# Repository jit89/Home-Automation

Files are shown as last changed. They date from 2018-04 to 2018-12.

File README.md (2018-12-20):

### Home-Automation: Thinking Differently
With the emergence of the IOT [(Internet of Things)](https://en.wikipedia.org/wiki/Internet_of_things) , automation has become a part and parcel of our daily lives. Starting from lights and fans, people have started to automate almost everything around them. After software giants like Amazon and Google started providing cloud services, people came to use the free resources provided by them to store/log their data and manage them from a distance even without having direct physical contact with the devices.
After this was pretty well-exploited, people started combining the power of machine learning with the existing technology. With rapid improvement in hardware and GPU's becoming cheap, it has become quite easy for an individual to learn, test out and contribute to the advancement of machine learning. Powerful methods like use of [deep learning](https://en.wikipedia.org/wiki/Deep_learning) in visual image processing, natural langugage processing etc has made this existing technology even more smarter. Popular home assistants like Amazon [Alexa](https://developer.amazon.com/alexa) etc, by making their API's open sourced have encouraged development in home automation even more.
### Why re-invent the wheel then ?
You might ask, well a lot of people have spent years writing and perfecting their techniques, why not build our application atop them ? Why do we even need to think about something from scratch where we have already progressed so far ? The answer is very simple, in fact this the reason for which we took up this project. We couldn't agree well with the existing idea of automation. I know, there are some brilliant projects out there at [Instructables](https://www.instructables.com/), [Hackaday](https://hackaday.com/) and [Hackster](https://www.hackster.io/) etc where people have put a lot of effort making a very neat and appealing project and I appreciate their effort. But controlling lights, fans, switches and other power ports using bluetooth, WiFi and other technologies through a custom designed Android/iOS application may be excellent but they are over exploited already. Yeah, you can switch on your Television and washing machine, turn off the radio, feed your pet, monitor the weather while sitting on your couch while watching your favourite series on Netflix but this has already been done, right ? We are already living those days, but what if your TV knew when do you watch it mostly ? What if your lights and fans knew when to turn on and when not to so they could save the maximum power when you are not in in your room ? That is much better than controlling your lights, fans, television etc through a Bluetooth controlled Arduino or telling Alexa to switch it on/off for you. My point is, the devices which we use everyday should develop some kind of intelligence so that they can know when they are used mostly and thus turn themselves on during those hours without you, manually switching it on. This is exactly what we try to do here.
### The Idea
Keeping aside all big talks, our aim is simple, designing a system that learns to map user behaviour. Citing a small example here, Suppose, you live alone in small apartment with only three appliances in your house, two lights and a fan, lets call them **LIGHT 1**, **LIGHT 2** and **Fan**. Now, consider the following case:
* You wake up at 07:00 (7:00 AM) hours and do your daily chores.
* You leave for office at 08:00 Hours (8:00 AM).
* You return home at 19:00 Hours (7:00 PM).

You follow the above routine on most working days. After waking up (i.e is after 07:00) hrs and before leaving for your office at 08:00 hrs suppose you use light 1 and the fan. After returning from office, you use all three of the appliances. Since, you dont have many switches in the room, you don't have much room for exploring more options, as a result you follow a similar routine everyday.
If we use our prototype here, what our system will do is, it will learn when and how much you used the appliance and from the very next day try to follow the same routine as followed by you the previous days. This wont be done from the start, after you install the prototype it will observe you for a day which we call as the **observation period**.
### The Brief Technicalities
Its time for us now, to dive into brief technical details. Our application is actually a room automation module which is used to automate your room, this module provides a drop in replacement for your switchboard so that you do not need to touch your switch board again. The form factor of the module will be so made that it retro-fits behind your switchboard. You can then control the functionalities of the physical switches of your switchboard through a smartphone application, just like any other home automation device. But Wait! There is much more to it. Apart, from controlling them at your own will from the smartphone application you can very well control them by the physical switches if you like. We are not taking away your rights over your switchboard! This, comes in handy if the module or the smartphone application goes haywire, you can anyway use your switches without any worry. Wait, There is even more! Like I said before, the system takes into account your choices of switching appliances on and off both through the physical switches and through the smartphone device. After it has gathered enough data and after you allow it to, it will predict what appliance you might switch on at a certain time of the day and switches on that appliance. Its like, you come home everyday at 19:00 hrs (7:00 PM) and switch on the fan hanging over your sofa, but one day you find out as soon as you come home at or after 19:00 hrs (7:00 PM) the fan switches on by itself!
### Some Additional features
1. A lot of features have been mentioned already but what I would like to add here is, such a system works by mapping user action throughout the day and reproducing them later. Well, you might say, OK, I agree that someone can maintain some coherence in his/her routine for a day or two, but someone cannot follow the same pattern for days after days, for Heavens's sake we are not machines! We, too thought about this, how you will deal with your home appliances tomorrow cannot be exactly predicted by observing how you dealt with them today, we can only get a rough idea. If you observe someone for a day, the conclusion you will reach will be an abstract idea, like:
  > "Ohh, so he likes to leave all lights on during the night",

  or maybe something like this:

  > "Ohh, he switches on more tubelights in the night than in the day",

  or, more likely something like this:

  > "I bet, he uses only half of the appliances he has, in his house".

These are all rough estimates which might be true for a day or two but cannot be guaranteed over a longer period of time. So, How do you get make good estimtes ? Well you keep a watch more frequently and try to understand how much the behaviour of the user differs each day and update your observation accordingly. Our system exactly does that, it keeps a note of your usage behaviour very frequently and tries to draw and inference from that, after a day is over it updates its observations.

2. Since, the system follows the user's behaviour and updates itself as soon as the user's behaviour changes, the device isnt affected by the change of seasons, timezones, geographic locations etc. It all depends on how you use it. 
### How is it being done ?
Before starting, let me tell you quite frankly, that the idea is still in the developmental stage and a lot of community help is required to further polish it. Only a working prototype is being developed here. Our goal is to make a small, easy-to-interface  embedded module made from commonly available parts which will be having enough intelligence to provide descisions based on observing a particular user.
* Lets, talk about the hardware first, We are using [ESP8266-ESP12](https://www.elecrow.com/download/ESP-12S_User_Manual.pdf) [Wemos D1 Mini](https://wiki.wemos.cc/products:retired:d1_mini_v2.2.0) here. 
  * Three pins are configured as outputs for controlling a relay through a BJT (Bipolar Junction Transistor) or probably a MOSFET in the future, for switching high voltage appliances. 
  * A [PIR (Passive Infrared Sensor)](https://cdn-learn.adafruit.com/downloads/pdf/pir-passive-infrared-proximity-motion-sensor.pdf) is used to detect the occupancy of a person in the room, the output of the PIR sensor is fed to a pin configured as input. 
  * For storing the data permanently an i2c [FRAM](http://www.cypress.com/file/136491/download) will be used, FRAM being chosen particularly because of its fast write time and very large read/write cycles in comparison to any eeprom or flash memory.
* The software used to program the ESP is micropython. They are seriously brilliant guys who made micropython possible. I would suggest you to take a look at ther [repository](https://github.com/micropython/micropython) for more information. The software will manage all the afore mentioned hardware. A small single neural network with a single hidden layer will be employed to predict the appliance which needs to be turned on/off, given a particular time and a state (i.e the person is in the house or not). Please note that we are not doing a time series prediction anyway, we are not trying to model the user's behaviour as time series beacuse such a series would be very stochastic, it would more and more difficult to find a pattern in the user's behaviour if the observations are taken for a very long period of time. Our model is based on the assumption that the chance of the user,  using our system, to repeat his/her routine is maximum the very next day, i.e if today is Tuesday, there is more probability of the user to follow a similar routine for Wednesday, but would be very difficult to say in advance that the user will follow a similar routine on Saturday or Sunday. Obviously, hard coding such an assumption is a very naive choice indeed because there can be many cases which might simply outrun the assumption, but for the sake of simplicity such an assumption is made. But some other methods are also employed to alleviate the issue. 
* A smartphone application is being developed too for user access through a smartphone.
* A server side script which the ESP8266 and the smartphone application will connect to enable the user to acces the home appliances from anywhere in the world. The server side script will be written in CPython. We intend to buy a domain for this purpose.

### The occupancy detection algorithm
Since, we have already talked about the hardware and the software separately, its time we combine both of them to state an algorithm followed by the system. A little note here, we are using PIR to detect if a person is present in the room, once the person gets out of his/her room we switch off the appliances present in the room when the user gets back inside, the appliances switch on. But do all of them switch on ? No, only those appliances switch on, which have been switched on by the user in the previous days when the system was observing the user during the **observation period**. This essentially means, once you come inside of your room you need not switch on your home appliances yourself, the system does it for you, it remebers what appliances you had switched on during that time in the previous days, and switches on that appliance which has a high probability of being switched on by you during that time.
Now we can discuss about the occupancy detection algorithm, our idea is inspired from [this](https://www.researchgate.net/publication/308007740_Predicting_room_occupancy_with_a_single_passive_infrared_PIR_sensor_through_behavior_extraction) paper. The paper discusses sophisticated filtering and detection methods none of which are employed here, still its worth a read if you are into mathematics and love reading articles related to applied machine learning. The only part of our idea taken from the paper is that we are using only a single PIR. What we previously did was to keep two PIR's kept at a distance from each other in a fashion that is described in the left portion of the picture below:
    
    Our earlier layout                                  |                      PIR Filed of Vision       
    --------------------------------                    |                   -
          ---                                           |                 -
      PIR 1  |--                                        |               -
             |  |                                       |             -
             |--                                        |           --
          ---                                           |  ---    -    --
                                                        |     |--        --
    ----------------------------------                  | PIR |  |         -    120*
                                                        |     |--          -
    ----------------------------------                  |  ---    -       --
          ---                                           |           -   --
      PIR 2  |--                                        |             -
             |  |                                       |                -
             |--                                        |                   -
          ---                                           |                     -
    ----------------------------------                  |  

So, whenever someone crossed PIR 1, the output pin of the PIR 1 became high, and then after he crossed PIR 2, its output became high, we connected the output of the two PIR's to an Arduino and enabled both the arduino pins to fire interrupts whenever the state of the pin changed from low to high. Inside the interrupt service routine (ISR), which is the section of the code that gets executed during an interrupt occurs, we stored a timestamp. Now, suppose, when the person crosses PIR 1 we store the time stamp in a variable named **t1**, now when he crosses the PIR 2, we store the timestamp in a variable caleed **t2**. Now, if t2 is greater than t1, it means the PIR 1 fired before the PIR 2 and the person crossed PIR 1 first, we classified this movement as entry, if the opposite happened i.e if t1 was greater than t2, that is the person approached PIR 2 first and then PIR 1, we classified it as an exit. The method is simple enough but has many drawbacks like you have to cross the two PIR's linearly, also the field of vision of the PIR's are 120 degrees as drawn on the right side, so placing two PIR's side by side will cause their field of visions to overlap and it may often happen that the two PIR's fire together, to avoid that, we used a cylindrical enclosure to cover the PIR's partially, so that their field of vision's are forcibly narrowed, this wasn't a good practice and reduced the efficiency of PIR sensors and sometimes leading them to not fire at all.

After this, we came to the idea of using a single PIR after reading that research paper which I talked about earlier. We still connect the output of the PIR to our ESP and enable the pin to detect a rising edge. What we only dont do now is use another PIR, we let the single PIR fire freely on its own. If I haven't already talked about the delay in the PIRs, I'm going to talk about it now, if you have used a PIR before, then you might be knowing that after the PIR output pin has become high it stays high for a certain amount of time. While the PIR output is high it caanot detect any motion during that period. So, this is the minimum amount of time every PIR will wait before being available to take another reading. The delay varies across PIRs and I have rarely found two PIR sensors having the exact same amount of delay. The delay can be increased as well using the preset given in the PIR sensor board but for our use we keep it at its minimum. 
What we do now is, **sample the PIR output pin after every 5 seconds**, we define a quantity called activity which sees how many times we get a HIGH output from the PIR during a given span of time, here, the span being 1 hour. The PIR will fire only when a person moves inside the room. Thus if the person becomes motionless the PIR won't output a HIGH, so counting the HIGH states sampled from the PIR means to indirectly measure how much the person makes movement during his entire stay inside the room. But we are not just counting the number of HIGH outputs from the PIR and dividing it by 3600 seconds to get an average rate of HIGH fires or activity of the person. Why ? Because averaging out is a good solution to get a rough measure of the user activity inside the room but vital information like the minimum rate and the maximum rate during the person's stay in his room in an hour cannot be found out from the average. So, we keep track of the changes in the activity variable and keep two other variables for storing the maximum and the minimum activity during an hour of observation.

We will try to follow the below mentioned tree:

    ----root
        |----Hardware
                |----Schematics, datasheet and pcb design files
        |----Micropython
                |----Micropython code for the Esp
        |----Server
                |----Server side scripts
        |----Smartphone_Application
                |----All documentation related to the smartphone application

### Support
We would appreciate any help provided from your side in designing and developing this idea. We also welcome all kinds of comments and suggestions provided to us.

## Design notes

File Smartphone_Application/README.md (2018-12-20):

<h1>HOME APP</h1>

## Xml Formatting
In designing xml of this app navigation drawer layout is used
* All mainscreen elements are inside a frame layout.
* A linear Layout is used after frame Layout to support elements
* Several layers of layouts were used to hold various elements
A rough map of the xml layout  is given below:
    
    ----drawer_layout
                
             |--Frame_layout
                   |---Relative_layout
                           
                           |---Linear Layout(H)
                                        |--ImageButton
                                        |--TextView
                                        |--Imagebutton
                           |---Linear Layout(H)
                                        |--Linear Layout(v)
                                                    |--ImageButton
                                                    |--TextView
                                                    |--Seekbar
                                        |--Linear Layout(v)
                                                    |--ImageButton
                                                    |--TextView
                                                    |--Seekbar
                           |---Linear Layout(H)
                                        |--Linear Layout(v)
                                                    |--ImageButton
                                                    |--TextView
                                                    |--Seekbar
                                        |--Linear Layout(v)
                                                    |--ImageButton
                                                    |--TextView
                                                    |--Seekbar
                           |---TextView
                           |---Linear Layout(H)
                                        |--ImageButton
                                        |--ImageButton
                                        |--ImageButton
        
        |--Navigation_View
                        |---Header
                        |---Drawer Views
        
        |--Splashscreen

## MainActivity
* Separate boolean variables are assigned for every individual appliances of every room.
* On appliance button click it checks the concerned variable state and change the state accordingly 
and also change the text view.
* On Button or seekbar change it calls a method which sends a json to a hardcoded url.
* On room Button click it shows the status of the appliances of that room.

## Screenshots
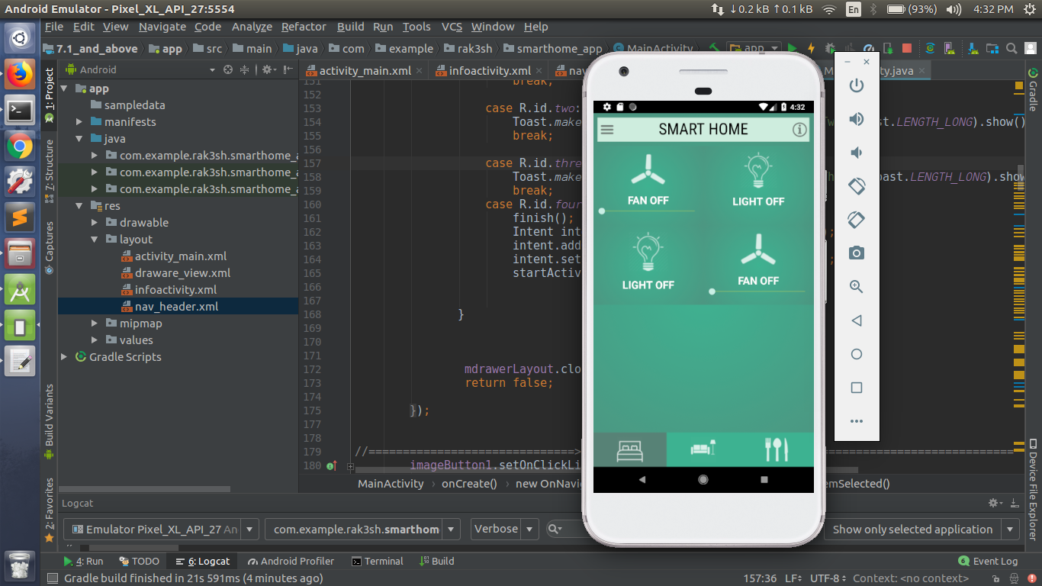
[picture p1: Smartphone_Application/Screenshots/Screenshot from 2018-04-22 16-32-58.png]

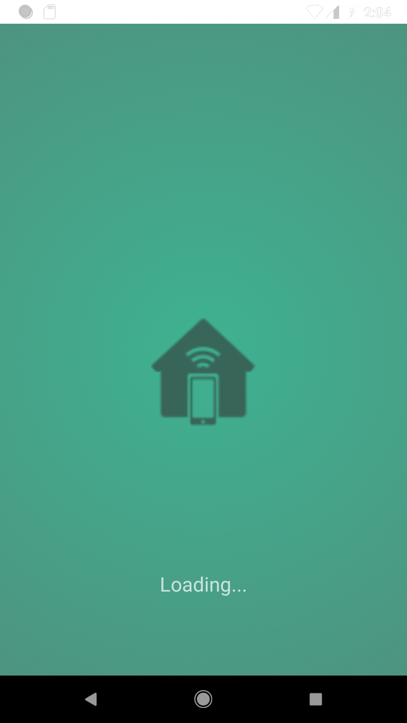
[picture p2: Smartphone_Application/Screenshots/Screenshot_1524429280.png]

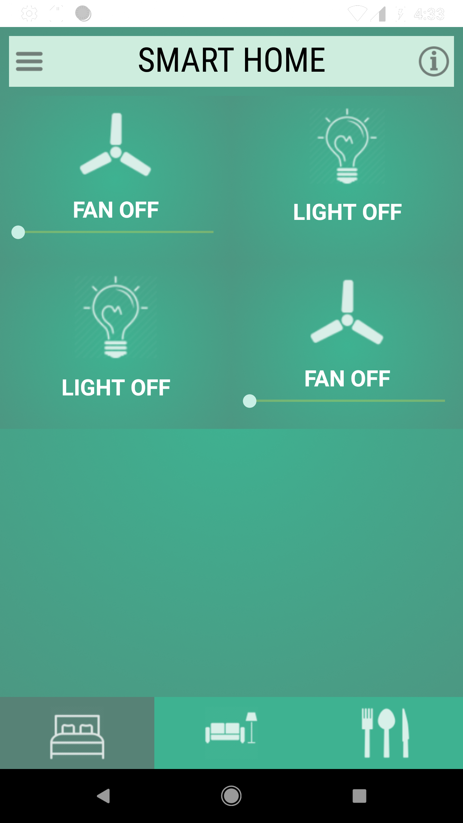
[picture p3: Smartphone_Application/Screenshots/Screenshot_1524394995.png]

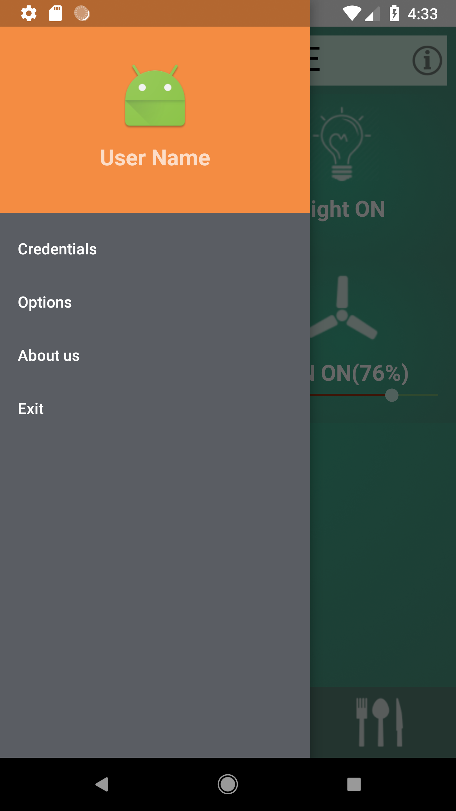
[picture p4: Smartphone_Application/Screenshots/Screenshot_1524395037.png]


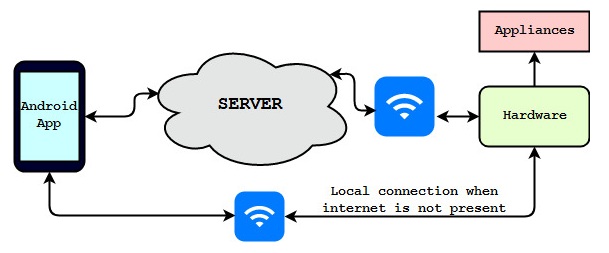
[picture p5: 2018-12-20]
Hardware/rev_1.0/Block_Diagrams/system.jpg

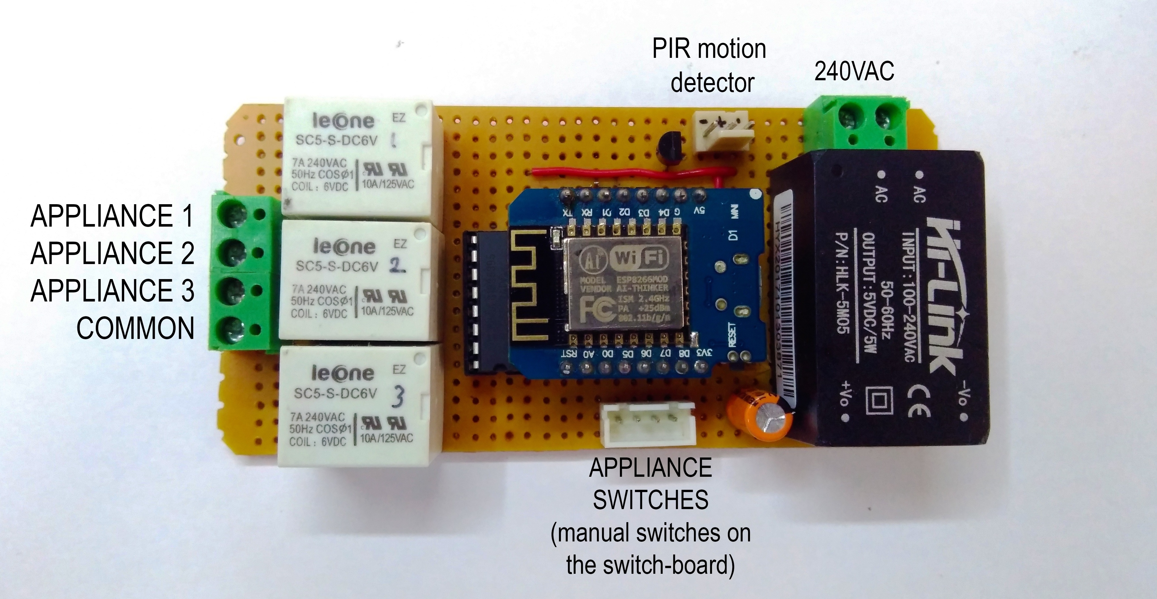
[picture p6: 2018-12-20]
Hardware/rev_1.0/Block_Diagrams/hardware_overview.jpg

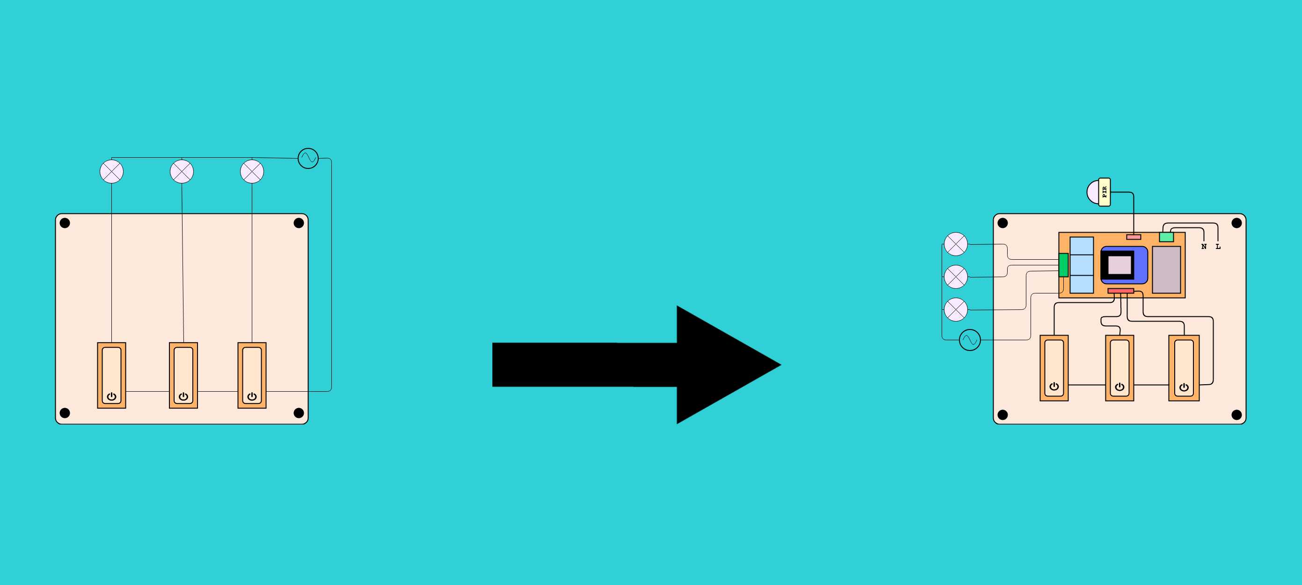
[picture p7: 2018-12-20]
Hardware/rev_1.0/Block_Diagrams/state_change.png

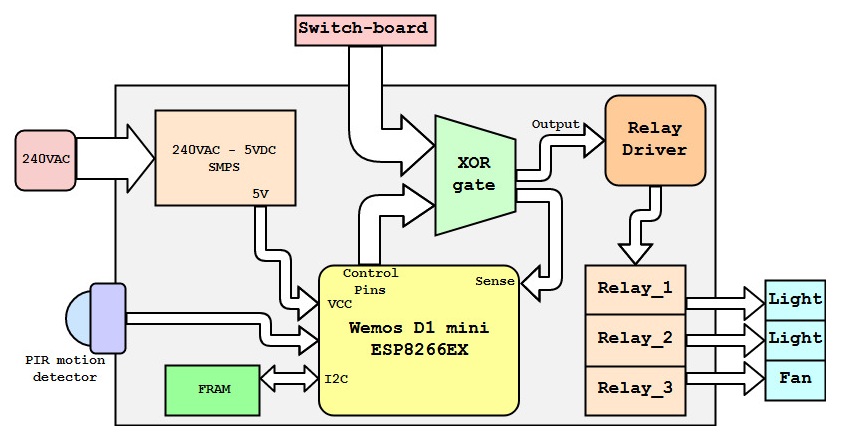
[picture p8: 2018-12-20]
Hardware/rev_1.0/Block_Diagrams/hardware_block_diagram.jpg

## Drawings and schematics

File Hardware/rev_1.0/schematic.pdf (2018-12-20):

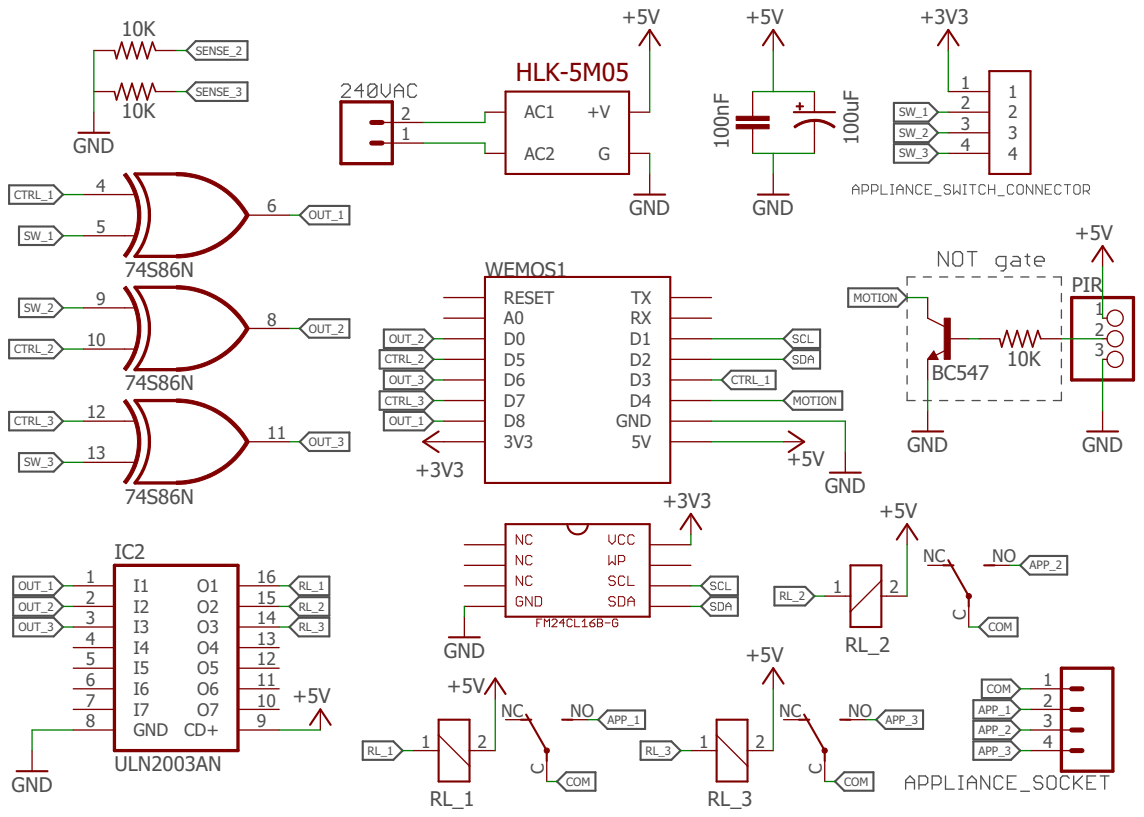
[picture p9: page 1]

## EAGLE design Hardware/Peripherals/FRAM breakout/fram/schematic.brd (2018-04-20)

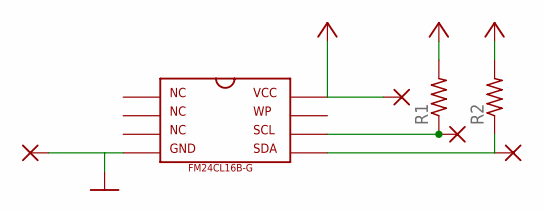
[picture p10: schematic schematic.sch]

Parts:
GND: SMD2; SMD1,27-2,54
R1, R2: R-US_M0805; M0805
SCL: SMD2; SMD1,27-2,54
SDA: SMD2; SMD1,27-2,54
U$1: FM24CL16B-G
VCC: SMD2; SMD1,27-2,54

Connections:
+3V3: R1.2, R2.2, U$1.8, VCC.1
GND: GND.1, U$1.4
unnamed: R1.1, SCL.1, U$1.6
unnamed: R2.1, SDA.1, U$1.5

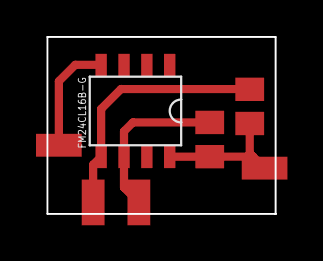
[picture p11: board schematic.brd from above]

Board: 2 copper layers, 12.7 x 9.8 mm, 7 parts (0 on the bottom side), 4 nets.

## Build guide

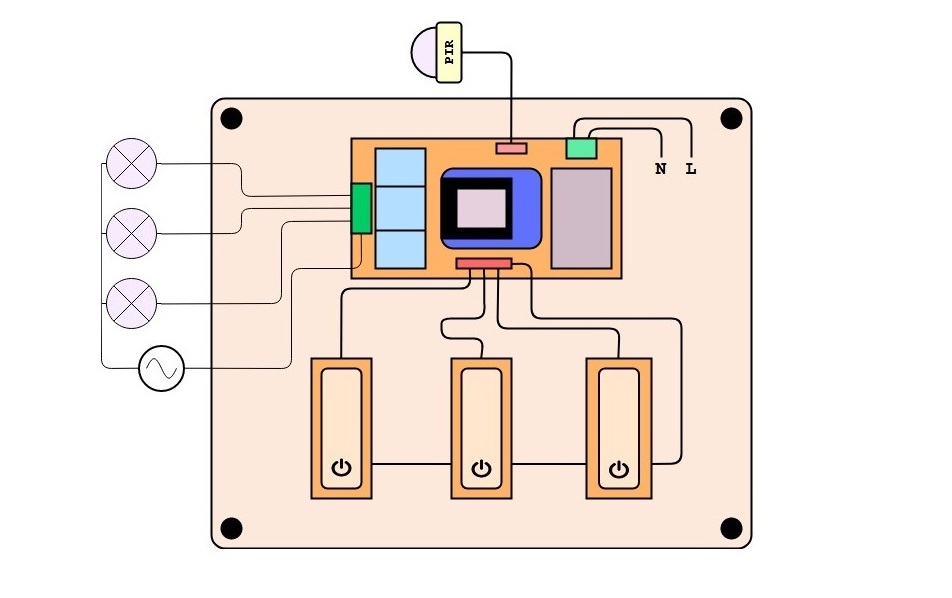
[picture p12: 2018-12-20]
Hardware/rev_1.0/Block_Diagrams/wiring.jpg

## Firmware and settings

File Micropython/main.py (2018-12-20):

import machine
import network
import urequests
import utime
from machine import Pin

from Micropython.appliance import Device
from Micropython.utils import rtc_init, station, timed_function

rtc = machine.RTC()
i2c = machine.I2C(sda=Pin(4), scl=Pin(5), freq=400000)

sta = network.WLAN(network.STA_IF)
ap = network.WLAN(network.AP_IF)

old_req = None


def test_device_stagnancy(device_list):
    for device in device_list:
        device.calibrate_stagnancy()


@timed_function(500)
def parse_request(device_list):
    global old_req

    try:
        req = urequests.get('http://phpexampl.000webhostapp.com/test.php?opt=x')
    except:
        req = urequests.get('http://phpexampl.000webhostapp.com/test.php?opt=x')

    req = req.json()

    if req != old_req and old_req is not None:

        if req['app11'] != old_req['app11']:
            device_list[0].toggle_state()

        if req['app21'] != old_req['app21']:
            device_list[1].toggle_state()

        if req['app31'] != old_req['app31']:
            device_list[2].toggle_state()

    old_req = req


@timed_function(1000)
def print_debug_info(device_list):
    for device in device_list:
        print(device._output_pin.value())


def init():
    """All initialisations here"""

    # device_timer = machine.Timer(-1)

    output_pins = (00, 14, 13)  # Define your output pins here
    input_pins = (15, 16, 12)  # Define your input pins here

    devices = [Device(Pin(In), Pin(Out)) for In, Out in zip(input_pins, output_pins)]

    #   Set all the devices to zero state at first
    for device in devices:
        device.set_state(0)

    # ssid, password = access_point(sta, ap)
    station(sta, ap, 'D-Link', 'ik1224kln')

    rtc_init(rtc, sta)
    print(utime.localtime())

    # device_timer.init(period=60000, mode=machine.Timer.PERIODIC, callback=lambda _: test_device_stagnancy(devices))

    return devices


def main():
    # init()

    device_list = init()

    while True:
        """All routines that are repeated"""
        parse_request(device_list)
        print_debug_info(device_list)
        print('#')

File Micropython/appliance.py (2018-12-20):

import machine
import utime


# noinspection SpellCheckingInspection
class Device(object):
    """
    Device class for the appliances
    :param: _input_pin
    :type: machine.Pin object

    :param: _output_pin
    :type: machine.Pin object

    :return: None
    """

    def __init__(self, _input_pin, _output_pin):

        if isinstance(_input_pin, machine.Pin):
            self._input_pin = _input_pin
            self._input_pin.init(mode=machine.Pin.IN)
        else:
            raise TypeError("Expected argument 1 to be of type machine.Pin but got type {}".format(type(_input_pin)))

        if isinstance(_output_pin, machine.Pin):
            self._output_pin = _output_pin
            self._output_pin.init(mode=machine.Pin.OUT)
        else:
            raise TypeError("Expected argument 2 to be of type machine.Pin but got type {}".format(type(_output_pin)))

        self.DEVICE_DATA_STORAGE_ADDRESS = 80

        self._data = bytearray(24 * 7)  # Represent 24 hours * 7 days as a contiguous block of bytes

        self.on_time = 0
        self.oldHour = utime.localtime()[3]

    def get_state(self):
        """
        Returns the state of the _input_pin
        :param: None
        :return: Boolean
        """
        # noinspection PyArgumentList
        return self._input_pin.value()

    def set_state(self, value):
        """
        Sets the state of the _output_pin
        :param: value
        :type: Boolean
        :return: None
        """
        self._output_pin.value(value)

    def toggle_state(self):
        """
        Toggles the state of the _output_pin
        :param: None
        :return: None
        """
        self._output_pin.value(not self._output_pin.value())

    def get_data(self):
        # noinspection SpellCheckingInspection
        """
        Returns the data as bytearray
        :return: bytearray
        """
        return self._data

    def set_data(self, day, hour, value):
        if not isinstance(value, int):
            raise TypeError("Expected argument type int but got type {}".format(type(value)))

        if not isinstance(day, int):
            raise TypeError("Expected argument type int but got type {}".format(type(day)))

        if day > 6:
            raise IndexError("bytearray index out of range")

        self._data[24 * day + hour] = value

    def calibrate_stagnancy(self):
        """
        Determine the time for which the device was on and set _data according to a threshold
        :return: None
        """

        #   utime.localtime()[3] = hour
        if utime.localtime()[3] != self.oldHour:
            divfactor = 60.0  # A float

            #   utime.localtime()[6] = weekday
            self.set_data(utime.localtime()[6], self.oldHour, int(self.on_time / divfactor > 0.3))
            self.oldHour = utime.localtime()[3]
            self.on_time = 0

        if self.get_state() == 1:
            self.on_time += 1

    def save_to_mem(self, i2c, memaddr):
        """
        Save _data to FRAM memory
        :param i2c: machine.I2C object
        :param memaddr: starting memory location for writing _data
        :return: length of bytes written
        """
        if not isinstance(i2c, machine.I2C):
            raise TypeError("Expected argument 1 to be of type machine.I2C but got type {}".format(type(i2c)))

        if not isinstance(memaddr, int):
            raise TypeError(" Expected argument 2 to be of type machine.I2C but got type {}".format((type(memaddr))))

        with Nointerrupts:
            i2c.writeto_mem(self.DEVICE_DATA_STORAGE_ADDRESS, memaddr, self._data)

        return len(self._data)

    def load_from_mem(self, i2c, memaddr):
        """
        Load _data from FRAM memory location
        :param i2c: machine.I2C object
        :param memaddr: FRAM memory location to read from
        :return:
        """

        if not isinstance(i2c, machine.I2C):
            raise TypeError("Expected argument 1 to be of type machine.I2C but got type {}".format(type(i2c)))

        if not isinstance(memaddr, int):
            raise TypeError(" Expected argument 2 to be of type machine.I2C but got type {}".format((type(memaddr))))

        with Nointerrupts:
            i2c.readfrom_mem_into(self.DEVICE_DATA_STORAGE_ADDRESS, memaddr, self._data)

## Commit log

2018-04-18 Buttons for different rooms Added
2018-04-18 room Button Funcitionally added
2018-04-20 new file: Hardware/FRAM breakout/fram/eagle.epf new file: Hardware/FRAM breakout/fram/gerber/mask.ps new file: Hardware/FRAM breakout/fram/gerber/solder.ps new file: Hardware/FRAM breakout/fram/outpu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
    [schematic.brd, schematic.sch]
2018-04-20 renamed: Hardware/FRAM breakout/FM24CL16B-G eagle library/FM24CL16B-G_fram.lbr -> Hardware/Peripherals/FRAM breakout/FM24CL16B-G eagle library/FM24CL16B-G_fram.lbr renamed: Hardware/FRAM breakout/fra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
    [schematic.brd, schematic.sch]
2018-04-22 schematic added
    [eagle_schematic.sch]
2018-04-22 schematic updated
2018-07-05 using volley instead of asynctask for http request. screen on start fixed
    [MainActivity.java]
